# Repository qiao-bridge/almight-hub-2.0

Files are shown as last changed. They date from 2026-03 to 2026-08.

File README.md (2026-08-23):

# almight-Hub 2.0

在面对普通场景下（键鼠、打印机、tf卡等）usb2.0的使用更加频繁，传统的usb2.0的hub功能单一，并不能应对更加复杂的场景。因此有了该项目——基于SL2.1A的全能型hub，能更好的应对接口扩展与转化、读取tf卡、串口的实现,更加重要的是其制作成本很少。
>——方便面

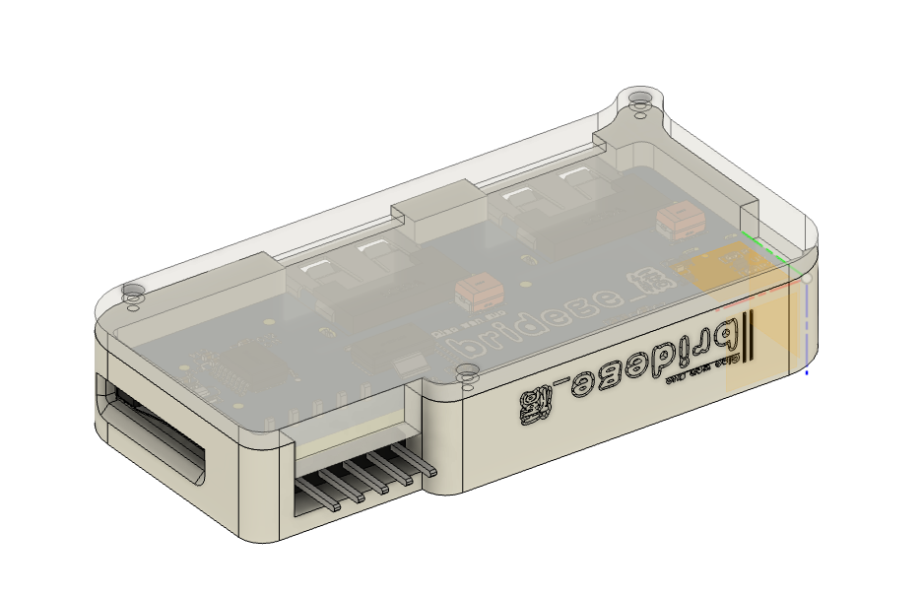
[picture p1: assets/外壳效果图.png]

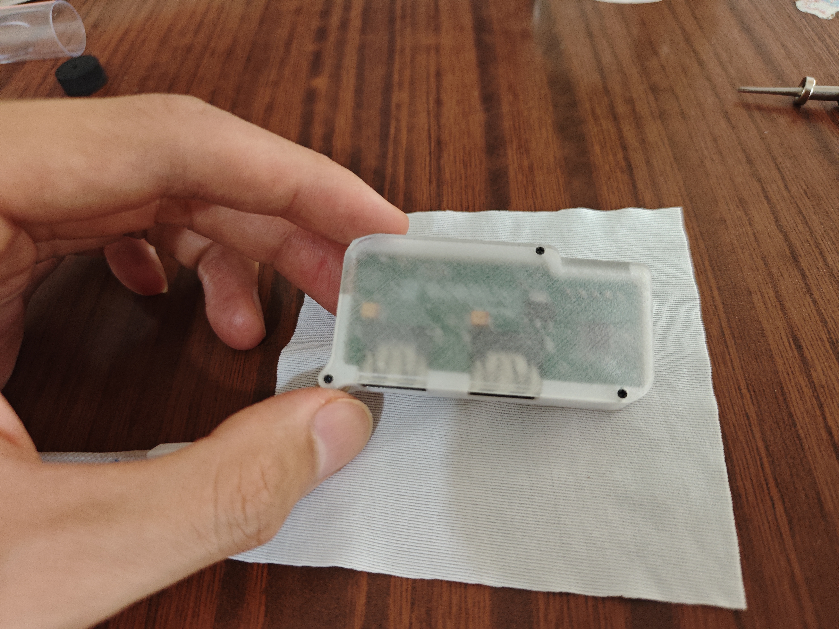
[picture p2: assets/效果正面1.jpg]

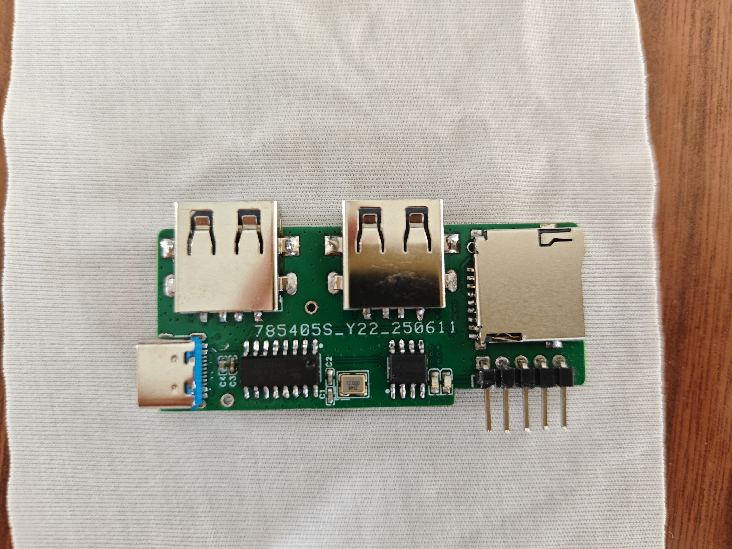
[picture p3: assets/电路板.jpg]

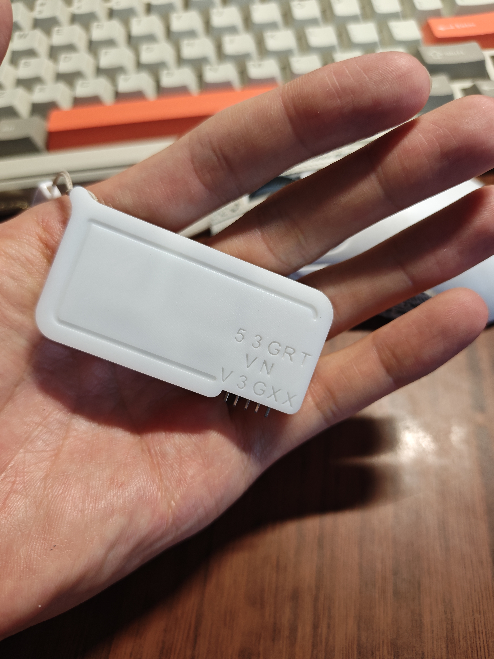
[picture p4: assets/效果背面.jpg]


## ✨ 特性
- 4口USB 2.0 HUB：基于SL2.1A芯片，稳定可靠
- TF卡读卡器：板载TF卡座，即插即用
- 串口（UART）引出：方便调试与开发
- 一体化3D打印外壳：结构紧凑，即插即用

## 📐 硬件架构
\`\`\`USB Input → SL2.1A Hub → [USB×2]+[TF Card]+[UART]\`\`\`

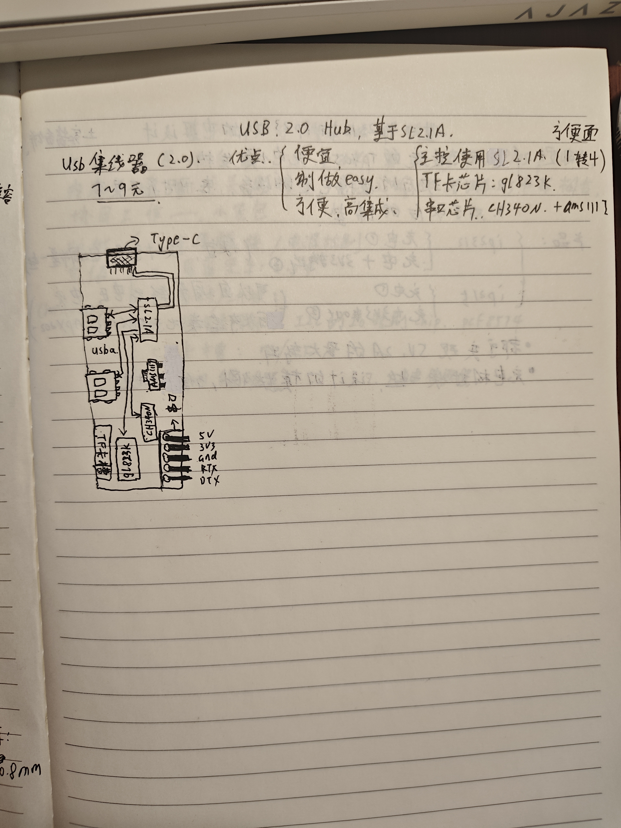
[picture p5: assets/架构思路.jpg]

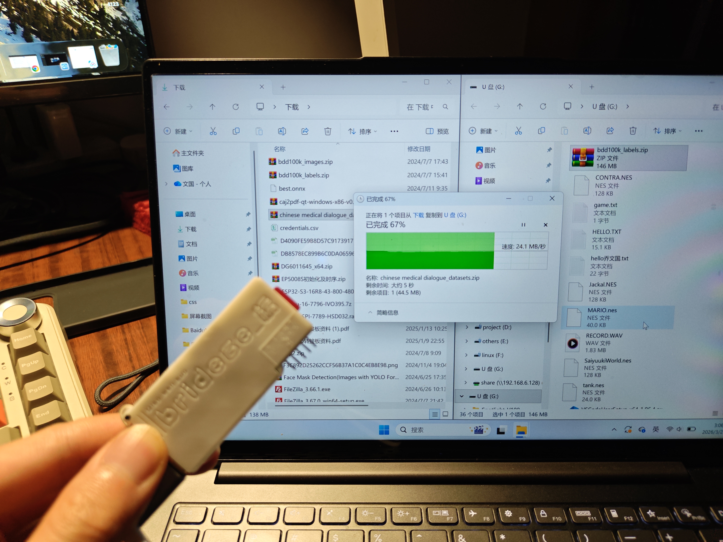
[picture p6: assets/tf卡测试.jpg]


## 🗂️ 目录说明
| 路径 | 内容 |
|---|---|
| `hardware/` | 嘉立创EDA工程、Gerber生产文件、原理图 |
| `enclosure/` | Fusion360外壳源文件 + STL打印文件 |
| `datasheet/` | 核心芯片数据手册 |
| `docs/` | BOM、组装说明、版本记录 |
| `assets/` | 渲染图、实物图 |

## 🚀 快速开始

### 直接打板/打印
- PCB：把 `hardware/gerber/` 发给PCB工厂
- 外壳：把 `enclosure/print/*.stl` 发给3D打印

### 自己修改
- PCB：嘉立创EDA专业版打开 `hardware/eda_project/ProDoc_hub_SL2.1A.epro2`
- 外壳：Fusion360 打开 `Hub_enclosure.f3z`

嘉立创开源广场：https://oshwhub.com/qiao_wen/almight-hub-20

## 📷 展示组装过程
> 注意在组装的过程中外壳与pcb卡的比较紧，因此保证每个器件的位置正确后，pcb与外壳先平行着然后在一起往下摁，见下图组装过程
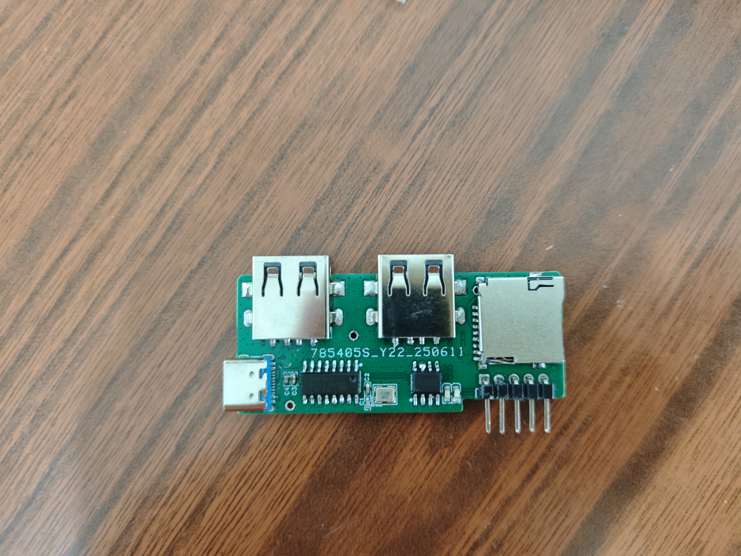
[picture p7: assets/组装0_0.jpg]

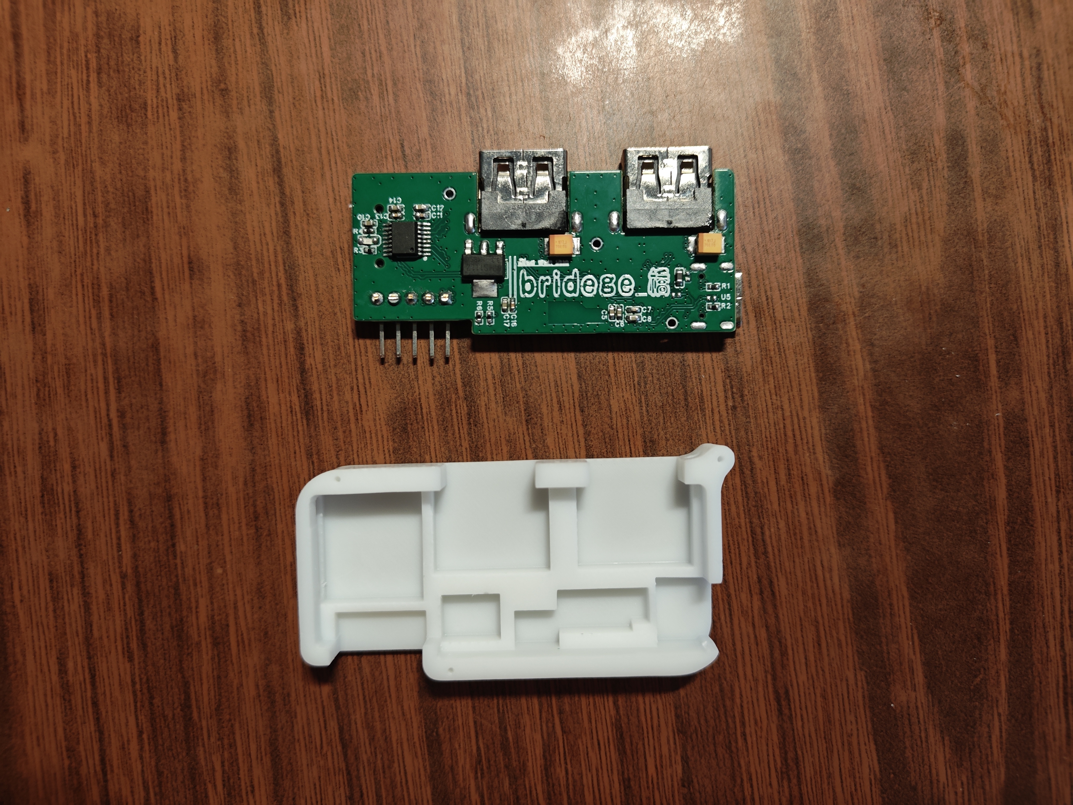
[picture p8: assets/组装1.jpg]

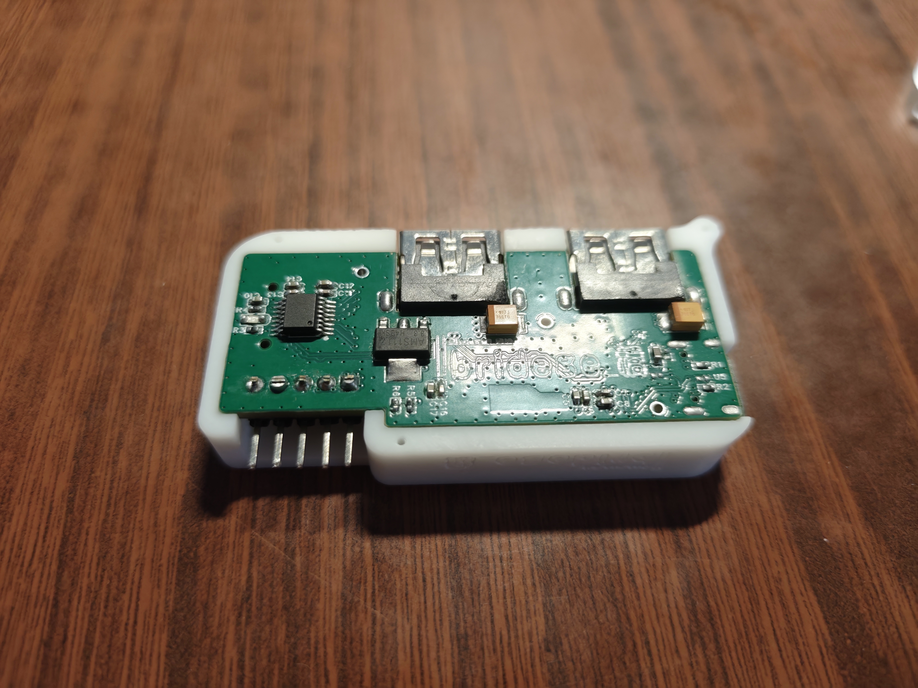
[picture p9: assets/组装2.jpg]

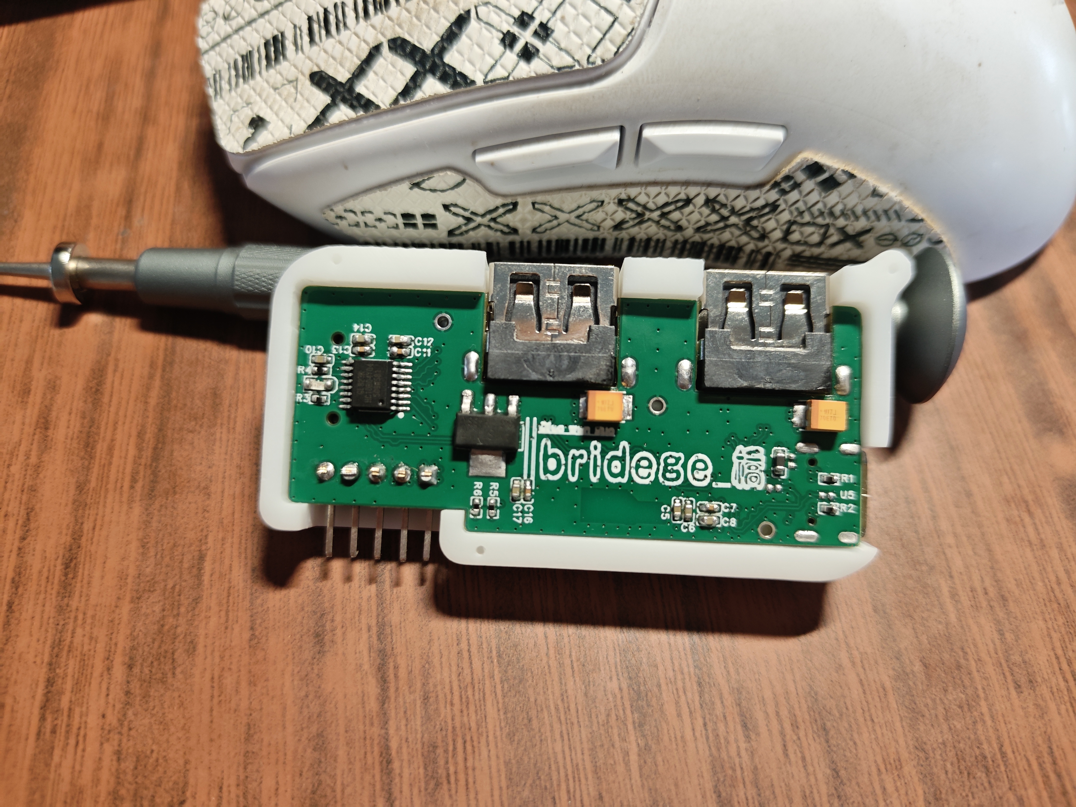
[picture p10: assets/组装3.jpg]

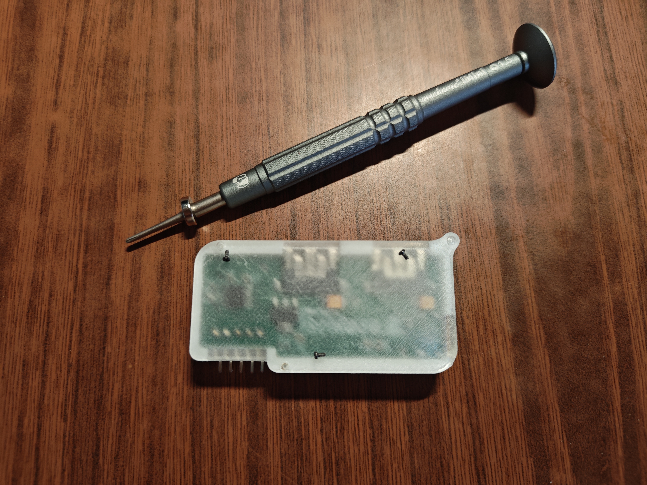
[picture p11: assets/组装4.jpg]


## 📋 BOM
详见 [docs/BOM_hub_SL2.1A.csv](docs/BOM_hub_SL2.1A.csv)

## 📄 License
GPL-3.0，详见 [LICENSE](LICENSE)

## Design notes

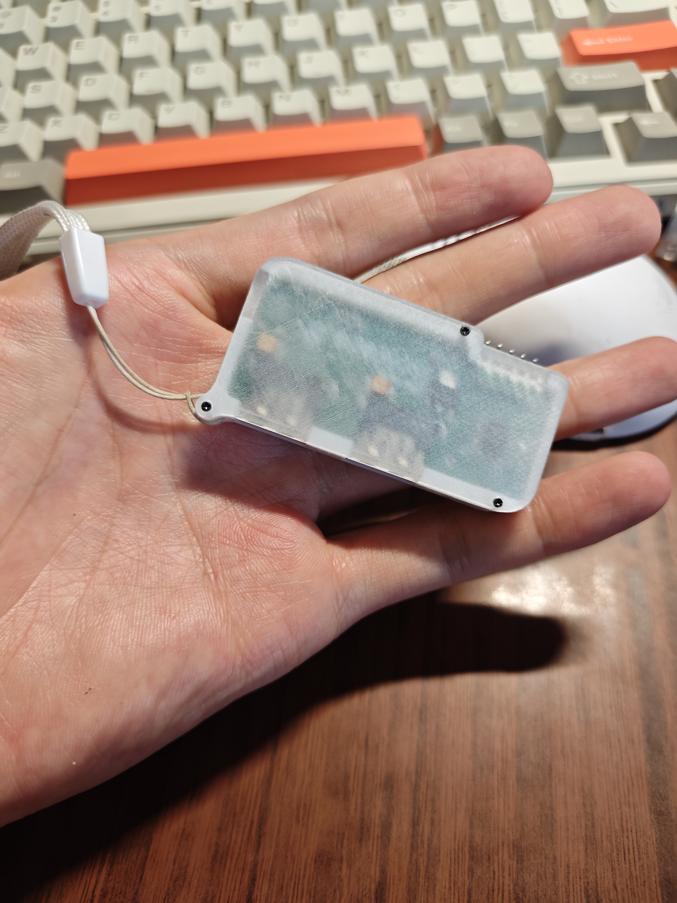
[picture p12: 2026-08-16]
assets/效果正面.jpg

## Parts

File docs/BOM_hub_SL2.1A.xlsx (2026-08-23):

No. | Quantity | Comment | Designator | Footprint | Value | Manufacturer Part | Manufacturer | Supplier Part | Supplier
1 | 2 | 20pF | C1,C2 | C0402 | 20pF | 0402CG200J500NT | FH(风华) | C1554 | LCSC
2 | 5 | 100nF | C3,C7,C11,C13,C16 | C0402 | 100nF | HGC0402R5106M100NTEJ | Chinocera(华瓷) |  | LCSC
3 | 8 | 10uF | C4,C5,C6,C8,C10,C12,C14,C17 | C0402 | 10uF | HGC0402R5106M100NTEJ | Chinocera(华瓷) | C7472949 | LCSC
4 | 2 | 100uF | C9,C15 | CASE-B_3528 | 100uF | TAJB107K006RNJ | Kyocera AVX | C16133 | LCSC
5 | 1 | TF-01A（就最常见的普通的） | CARD1 | TF-SMD_TF-01A |  | TF-01A | 韩国韩荣 | C91145 | LCSC
6 | 1 | 拍针（焊接后记得把背面多余的部分剪了，要不然盖不上）（弯） | H1 | HDR-TH_5P-P2.54-H-M-W10.4 |  | 拍针（弯） | XFCN(兴飞) | C492413 | LCSC
7 | 3 | led灯，颜色随便 | LED1,LED2,LED3 | LED0603-FD |  | A-SP192DGHC-C01-4T | Amicc(欧密格光电) | C19171301 | LCSC
8 | 3 | 5.1kΩ | R1,R2,R3 | R0402 | 5.1kΩ | RC0402FR-075K1L | YAGEO(国巨) | C105872 | LCSC
9 | 1 | 100kΩ | R4 | R0402 | 100kΩ | RC0402FR-075K1L | YAGEO(国巨) |  | LCSC
10 | 2 | 10kΩ | R5,R6 | R0402 | 10kΩ | RC0402FR-075K1L | YAGEO(国巨) |  | LCSC
12 | 1 | （typec 12pin）GT-USB-7010ASV | U1 | USB-C-SMD_G-SWITCH_GT-USB-7010ASV |  | GT-USB-7010ASV | G-Switch(品赞) | C2988369 | LCSC
13 | 1 | （磁珠，只要符合就大小，参数的话有啥选啥，）UPZ1608U221-2R2TF | U2 | L0603 |  | UPZ1608U221-2R2TF | Sunlord(顺络) | C279745 | LCSC
14 | 3 | （这个是tvs，如果不想买可以不焊接，影响不大）ESD5451N | U3,U5,U6 | DFN1006-2L-BI |  | ESD5451N | HXY MOSFET(华轩阳电子) | C5261080 | LCSC
15 | 1 | SL2.1A | U4 | SOP-16_L10.0-W3.9-P1.27-LS6.0-BL |  | SL2.1A | CoreChips(和芯润德) | C192893 | LCSC
16 | 1 | GL823K-HCY04 | U8 | SSOP-16_L4.9-W3.9-P0.64-LS6.0-BL |  | GL823K-HCY04 | GENESYS(创惟) | C284879 | LCSC
17 | 1 | CH340N | U9 | SOP-8_L5.0-W4.0-P1.27-LS6.0-BL |  | CH340N | WCH(南京沁恒) | C506813 | LCSC
18 | 1 | AMS1117-3.3 | U10 | SOT-223-4_L6.5-W3.5-P2.30-LS7.0-BR |  | AMS1117-3.3 | UMW(友台半导体) | C347222 | LCSC
19 | 2 | （USB A）U-A-24SD-W-2 | USB1,USB2 | USB-A-SMD_U-A-24SD-W-2 |  | U-A-24SD-W-2 | 韩国韩荣 | C2689986 | LCSC
20 | 1 | 12MHz | X1 | CRYSTAL-SMD_4P-L3.2-W2.5-BL | 12MHz | X322512MSB4SI | YXC(扬兴晶振) | C9002 | LCSC
21 | 螺丝M1*2的螺丝，仅仅给外壳用，不用固定主板，大概就用3个或两个， 固定外壳，有条件的话可以准备一条挂绳，细点
买元器件不用太刻意选择相应的型号，差不多就行了，不用太纠结（我说的是大部分）

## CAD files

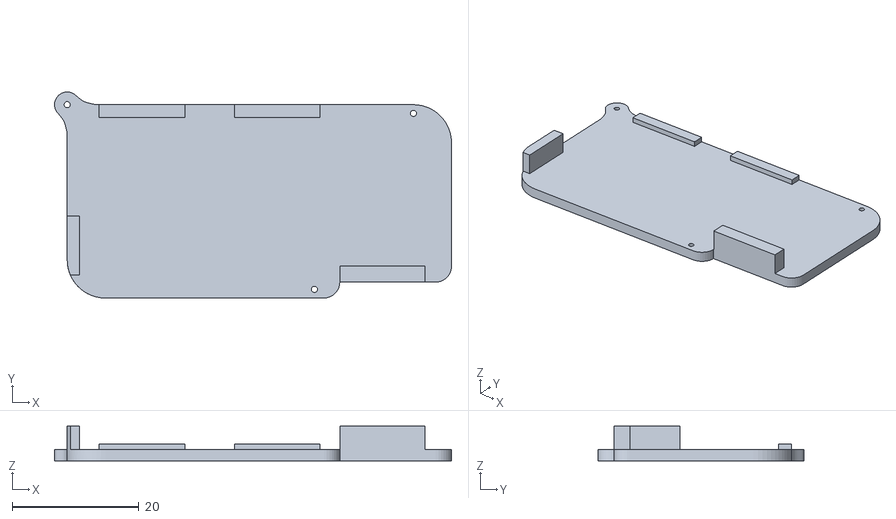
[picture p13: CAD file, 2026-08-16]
enclosure/print/上盖.stl
62.6 x 32.5 x 5.50

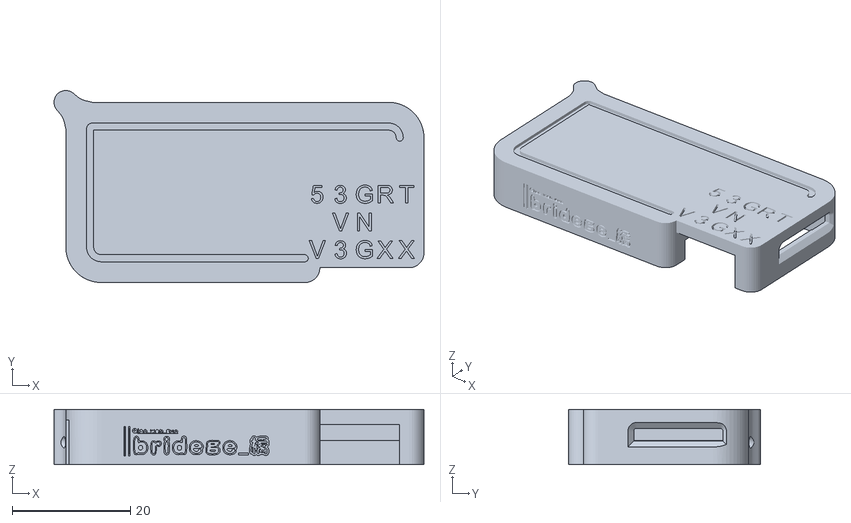
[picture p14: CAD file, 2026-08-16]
enclosure/print/下壳.stl
62.6 x 32.5 x 9.30

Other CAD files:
enclosure/source/Hub_enclosure.f3z

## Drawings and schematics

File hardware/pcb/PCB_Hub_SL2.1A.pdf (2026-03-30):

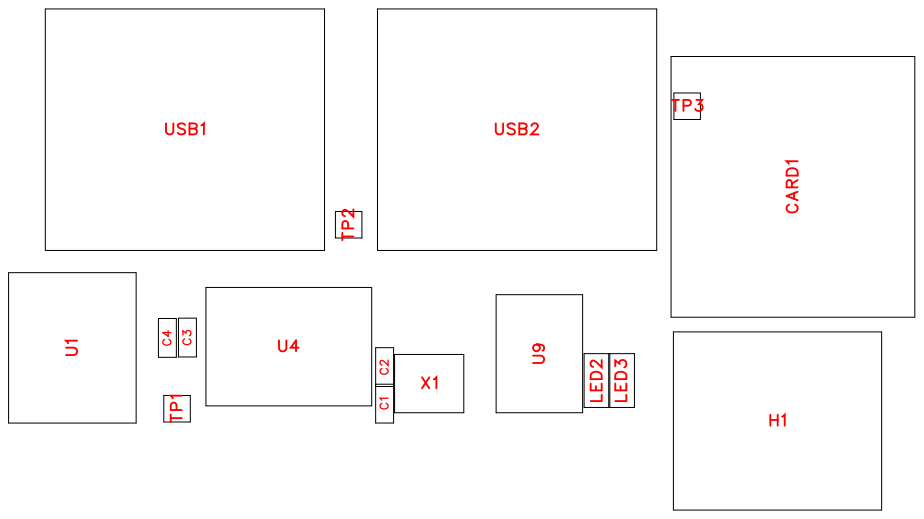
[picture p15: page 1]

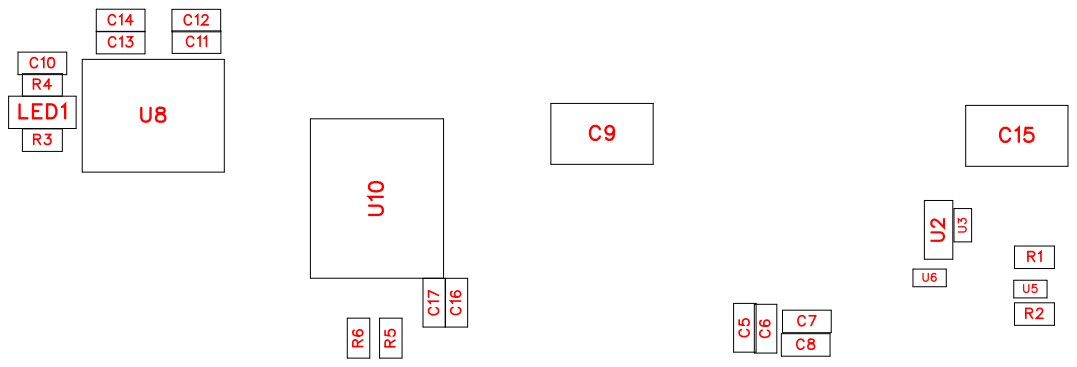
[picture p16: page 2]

No. | Quantity | Comment | Designator | Footprint | Value | Manufacturer Part | Manufacturer | Supplier Part | Supplier
1 | 2 | 20pF | C1,C2 | C0402 | 20pF | 0402CG200J 500NT | FH(风华) | C1554 | LCSC
2 | 5 | 100nF | C3,C7,C11,C13,C16 | C0402 | 100nF | HGC0402R5 106M100NT EJ | Chinocera(华 瓷) | | LCSC
3 | 8 | 10uF | C4,C5,C6,C8,C10,C12,C14, C17 | C0402 | 10uF | HGC0402R5 106M100NT EJ | Chinocera(华 瓷) | C7472949 | LCSC
4 | 2 | 100uF | C9,C15 | CASE-B_352 8 | 100uF | TAJB107K00 6RNJ | Kyocera AVX | C16133 | LCSC
5 | 1 | TF-01A | CARD1 | TF-SMD_TF-01A | | TF-01A | 韩国韩荣 | C91145 | LCSC
6 | 1 | 拍针（弯） | H1 | HDR-TH_5P-P2.54-H-M-W10.4 | | 拍针（弯） | XFCN(兴飞) | C492413 | LCSC
7 | 3 | A-SP192DG HC-C01-4T | LED1,LED2,LED3 | LED0603-FD | | A-SP192DG HC-C01-4T | Amicc(欧密格 光电) | C19171301 | LCSC
8 | 3 | 5.1k | R1,R2,R3 | R0402 | 5.1k | RC0402FR-0 75K1L | YAGEO(国巨 ) | C105872 | LCSC
9 | 1 | 100k | R4 | R0402 | 100k | RC0402FR-0 75K1L | YAGEO(国巨 ) | | LCSC
10 | 2 | 10k | R5,R6 | R0402 | 10k | RC0402FR-0 75K1L | YAGEO(国巨 ) | | LCSC
11 | 3 | M1螺丝孔 | TP1,TP2,TP3 | M1螺丝孔
12 | 1 | GT-USB-701 0ASV | U1 | USB-C-SMD _G-SWITCH _GT-USB-70 10ASV | | GT-USB-701 0ASV | G-Switch(品 赞) | C2988369 | LCSC
13 | 1 | UPZ1608U22 1-2R2TF | U2 | L0603 | | UPZ1608U22 1-2R2TF | Sunlord(顺络 ) | C279745 | LCSC
14 | 3 | ESD5451N | U3,U5,U6 | DFN1006-2L-BI | | ESD5451N | HXY MOSFE T(华轩阳电子 ) | C5261080 | LCSC
15 | 1 | SL2.1A | U4 | SOP-16_L10. 0-W3.9-P1.2 7-LS6.0-BL | | SL2.1A | CoreChips(和 芯润德) | C192893 | LCSC
16 | 1 | GL823K-HC Y04 | U8 | SSOP-16_L4 .9-W3.9-P0.6 4-LS6.0-BL | | GL823K-HC Y04 | GENESYS( 创惟) | C284879 | LCSC
17 | 1 | CH340N | U9 | SOP-8_L5.0-W4.0-P1.27-LS6.0-BL | | CH340N | WCH(南京沁 恒) | C506813 | LCSC
18 | 1 | AMS1117-3. 3 | U10 | SOT-223-4_L 6.5-W3.5-P2. 30-LS7.0-BR | | AMS1117-3. 3 | UMW(友台半 导体) | C347222 | LCSC
19 | 2 | U-A-24SD-W -2 | USB1,USB2 | USB-A-SMD _U-A-24SD-W-2 | | U-A-24SD-W -2 | 韩国韩荣 | C2689986 | LCSC

20

1 | 12MHz | X1 | CRYSTAL-S MD_4P-L3.2- W2.5-BL
12MHz | X322512MS
B4SI

YXC(扬兴晶 振)

C9002 LCSC

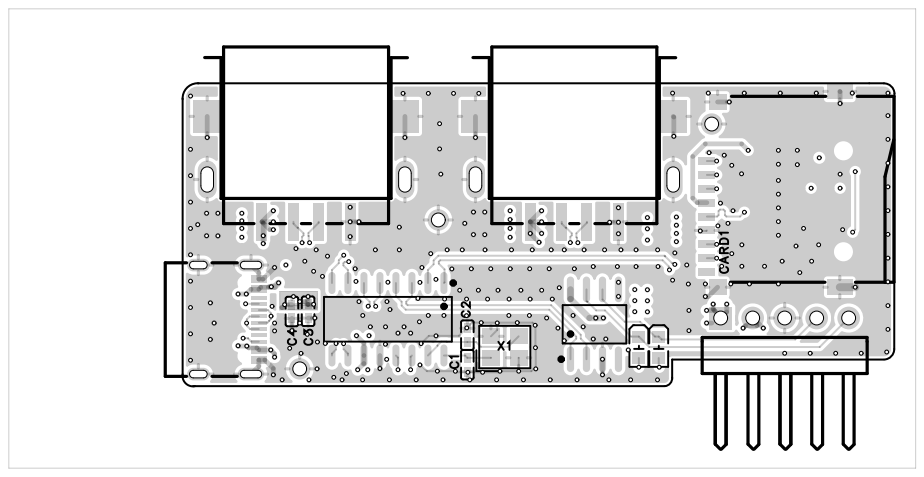
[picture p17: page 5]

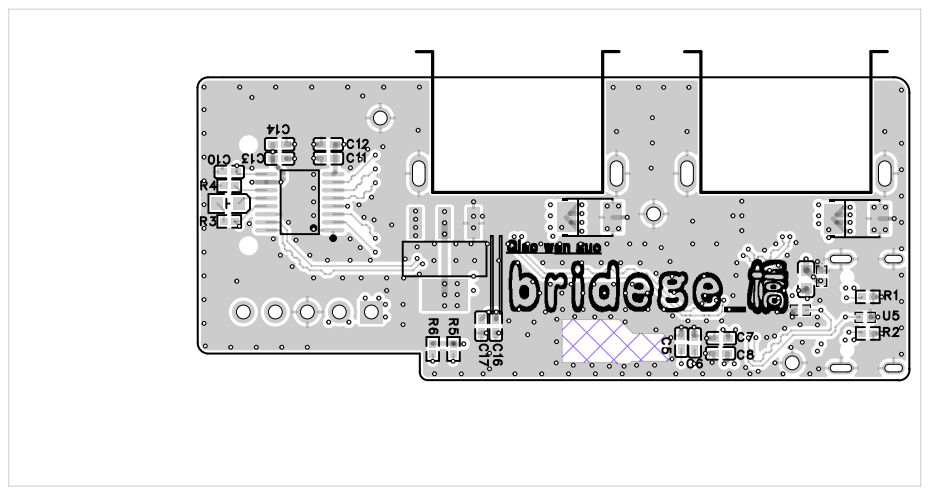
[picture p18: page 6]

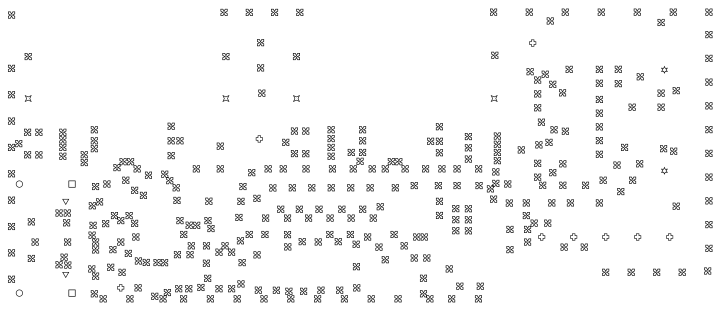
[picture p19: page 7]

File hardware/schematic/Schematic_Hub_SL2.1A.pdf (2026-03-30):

GND B1A12 VBUS B4A9 CC2 B5 SBU1 A8 DP2 B6 DN1 A7 DP1 A6 DN2 B7 CC1 A5 SBU2 B8 VBUS A4B9 GND A1B12

D+

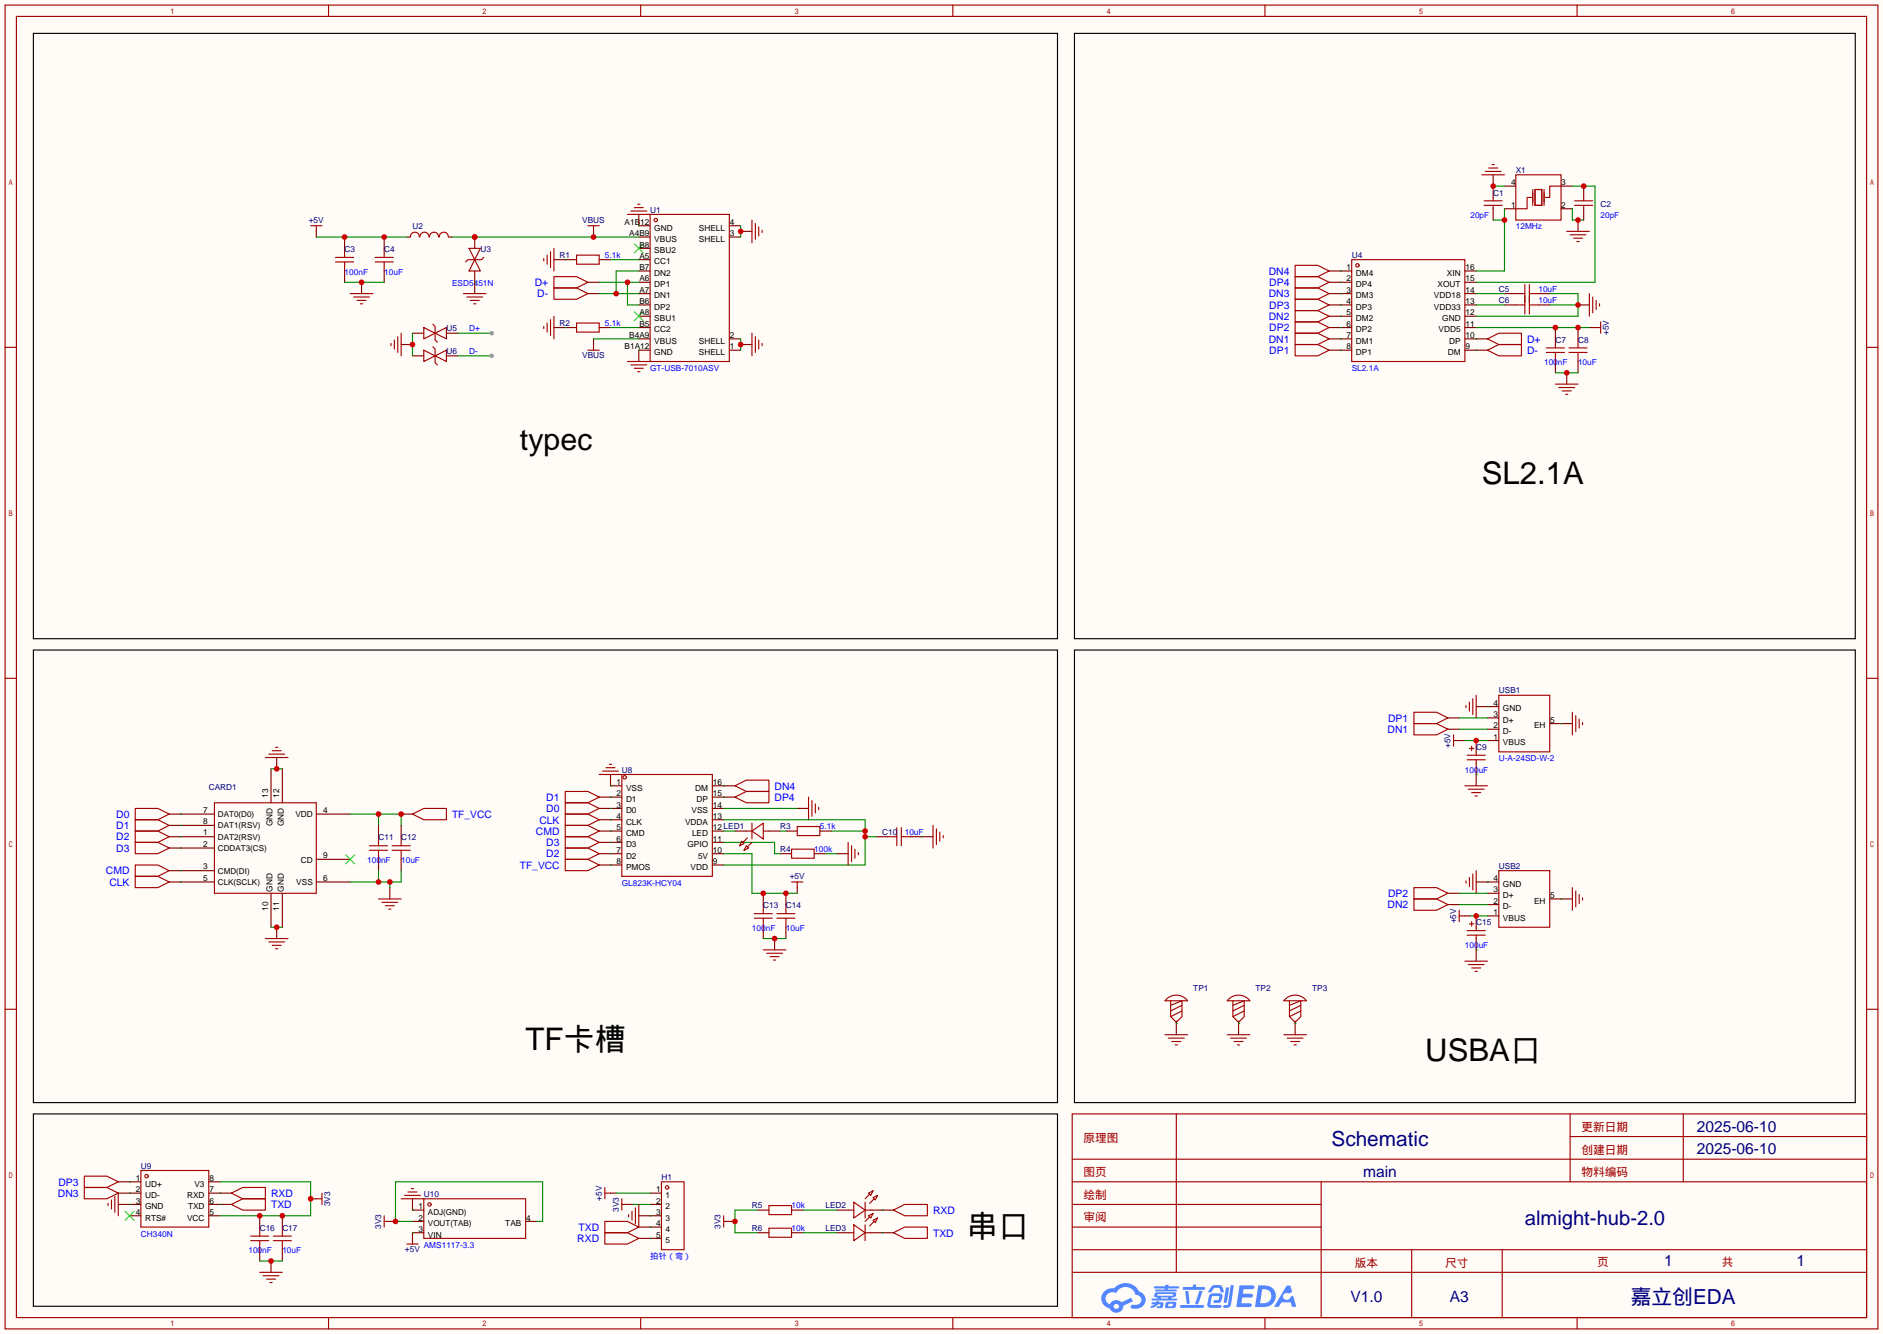
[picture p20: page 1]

5V 10 GPIO 11 LED 12 VDDA 13 VSS 14 DP 15 DM 16

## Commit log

2025-06-10 新建 datasheet
2025-06-10 新建 shell-外壳
2025-06-10 新建 schematic-原理图
2025-06-10 新建 bom
2025-06-10 外壳文件
    [hub_one.stl, hub_two.stl]
2025-06-10 板子相关文件
2025-06-10 数据手册
2025-06-10 bom表
    [BOM_main_PCB1_2025-05-21.xlsx]
2025-06-10 新建 pic
2025-06-10 图片信息
2025-06-10 readme文件
2025-06-10 remead提交
2025-06-11 [乔文国]更新板子模块
2025-06-12 [乔文国]更新外壳文件
    [hub_one.stl, hub_two.stl, 上盖.f3d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]
2025-06-13 [乔文国]外壳修改
    [going v27.step, hub_one.stl, hub_two.stl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]
2026-03-30 删除文件 .DS_Store
2026-03-30 重新整合
    [BOM_hub_SL2.1A.csv, BOM_main_PCB1_2025-05-21.xlsx, going v27.step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]
2026-03-30 更新readme
2026-08-09 文件结构更新
    [3D_model.step, BOM_hub_SL2.1A.csv, 上盖.stl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]
2026-08-10 更新外壳
    [3D_model.step, Hub_enclosure.f3z, 上盖.stl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]
2026-08-23 更新BOM表
    [BOM_hub_SL2.1A.xlsx]
